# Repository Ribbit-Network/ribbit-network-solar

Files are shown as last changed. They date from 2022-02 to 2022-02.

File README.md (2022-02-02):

## Introduction

In the future, it would be cool for the Frog Sensor to be solar-powered. This folder documents the progress towards making that a reality.

Due to supply-chain uncertainty and the potential for future changes to the Frog Sensor's architecture, initial development towards a solar-powered Frog is focused on developing a self-contained solar battery charging system designed to supply power to a either a Frog Sensor V1 (Raspberry Pi), a Frog Sensor V2 (Beaglebone Black), or any future version with a different processor.

## Development

Check out the following pages for more details on development progress:
- [Proof of Concept]()

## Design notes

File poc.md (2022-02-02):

# Proof of Concept

This document hopes to provide a record of early prototyping progress. As mentioned in the [readme](README.md), the initial goal is to develop a solar-charged battery system that can provide enough power to reliably operate the Frog Sensor.

## Electronics

The following assumptions were applied to the initial electronics design in order to reduce complexity:
- The battery will be a 2-cell series NiMH
- The solar panel will provide a regulated 5V supply 

### Schematic

### Parts List

| Description | P/N (w link) | Cost | Qty |
|---|---|---|-----|
| PMOS | | | |
| | | | |
| | | | |
| | | | |

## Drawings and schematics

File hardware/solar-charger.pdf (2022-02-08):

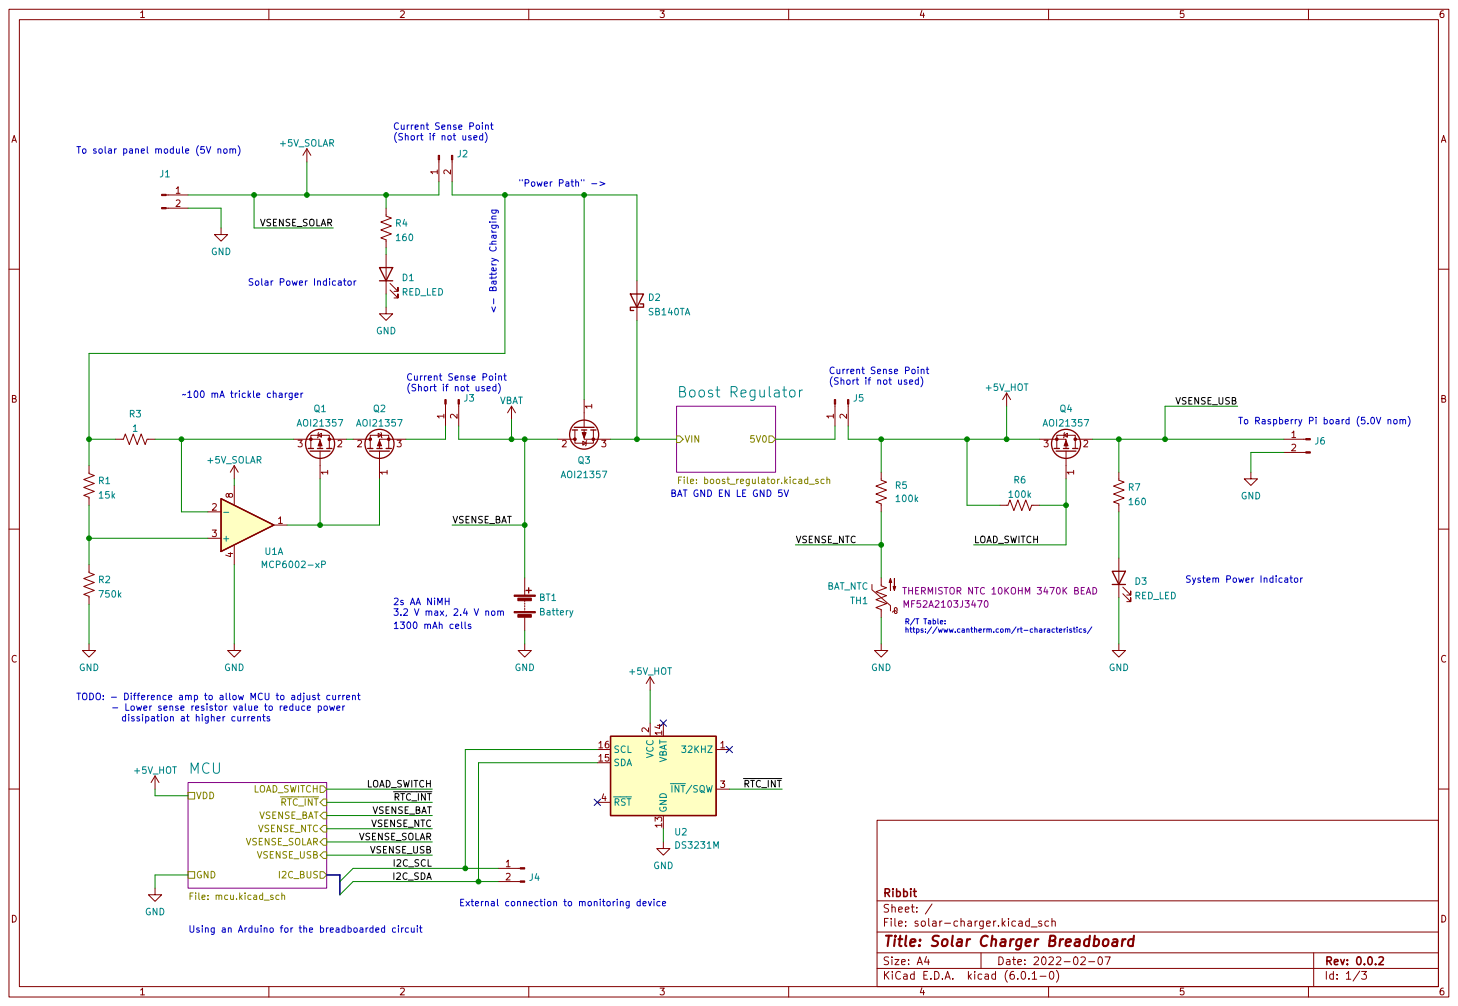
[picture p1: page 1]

To Raspberry Pi board (5.0V nom) 2s AA NiMH

TODO: - Difference amp to allow MCU to adjust current
- Lower sense resistor value to reduce power

VSENSE_SOLAR
File: solar-charger.kicad_sch Sheet: / Ribbit VSENSE_USB

External connection to monitoring device

Id: 1/3 Title: Solar Charger Breadboard

Using an Arduino for the breadboarded circuit

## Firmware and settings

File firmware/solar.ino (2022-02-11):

#include <avr/sleep.h>

#include <DS3231.h>
#include <Wire.h>

#define VSENSE_BAT   A0
#define VSENSE_NTC   A1
#define VSENSE_SOLAR A2
#define VSENSE_USB   A3

#define RTC_INTERRUPT 2
#define LOAD_SWITCH 10

#define CMD_READ_VOLTAGE    0xa1
#define CMD_SCHEDULE_SLEEP  0xa2

volatile int transaction_complete = true;
volatile int new_command = false;
volatile uint8_t command_response[2] = {0x0, 0x0};
volatile int rtc_alarm = false;

#define CMD_BUF_LEN 2
volatile uint8_t cmd_buffer[CMD_BUF_LEN];

void receive_command(int bytes_in) {
  transaction_complete = false;

  for (int i = 0; i < bytes_in; i++) {
    if (i < CMD_BUF_LEN) {
      cmd_buffer[i] = Wire.read();
    } else {
      // drop
      Wire.read();
    }
  }

  new_command = true;
}

void respond_command(void) {
  Wire.write(command_response[0]);
  Wire.write(command_response[1]);
  command_response[0] = 0;
  command_response[1] = 0;
  transaction_complete = true;
}

void switch_load_on(void) {
  rtc_alarm = true;
  digitalWrite(LOAD_SWITCH, LOW);
}

DS3231 rtc;
RTClib rtc_lib;

void setup() {
  pinMode(RTC_INTERRUPT, INPUT_PULLUP);
  pinMode(LOAD_SWITCH, OUTPUT);
  digitalWrite(LOAD_SWITCH, LOW);
  
  attachInterrupt(digitalPinToInterrupt(RTC_INTERRUPT), switch_load_on, FALLING);

  Serial.begin(115200);

  Wire.begin(0x8);
  Wire.onReceive(receive_command);
  Wire.onRequest(respond_command);
 
  sleep_enable();
  set_sleep_mode(SLEEP_MODE_PWR_DOWN);
}

void loop() {

  sleep_mode();
  // Code resumes here when woken by I2C address match interrupt
  Serial.println("Up!");
  if (rtc.checkIfAlarm(1)) {
    Serial.println("Alarm is ringing!");
    // switch load on
    digitalWrite(LOAD_SWITCH, LOW);
  }
  rtc.turnOffAlarm(1);
  rtc_alarm = false;

  if (new_command == true) {
    process_command(cmd_buffer);
    clear_buffer();
    new_command = false;
  }
  
  while(!transaction_complete);
  delay(10);
}

uint16_t read_pin(int analog_pin_num) {
  int analog_pin;
  
  switch (analog_pin_num) {
    case 0:
      analog_pin = VSENSE_BAT;
      break;
    case 1:
      analog_pin = VSENSE_NTC;
      break;
    case 2:
      analog_pin = VSENSE_SOLAR;
      break;
    case 3:
      analog_pin = VSENSE_USB;
      break;
    default:
      analog_pin = A0;
  }

  return analogRead(analog_pin);
}

int process_command(volatile uint8_t* cmd_buffer) {
  int rc = 0;
  Serial.print("cmd: "); Serial.println(cmd_buffer[0], HEX);
  switch(cmd_buffer[0]) {
      case CMD_READ_VOLTAGE:
      {
        // adc val is 10 bits, round down to 8 bits for command
        uint16_t pin_voltage = read_pin(cmd_buffer[1]);
        Serial.print("voltage: "); Serial.println(pin_voltage); 
        command_response[0] = (uint8_t) pin_voltage;
        command_response[1] = (uint8_t) (pin_voltage >> 8) & 0xFF;

        break;
      }
      case CMD_SCHEDULE_SLEEP:
      {
        // cmd_buffer[1] is number of seconds in the future to schedule (max 60 for now)
        DateTime time_now = rtc_lib.now();
        uint8_t new_seconds = (time_now.second() + cmd_buffer[1]) % 60;
        uint8_t new_minutes = time_now.minute() + (time_now.second() + cmd_buffer[1]) / 60;
        Serial.print(new_minutes); Serial.print("|"); Serial.println(new_seconds);
        rtc.setA1Time(time_now.day(), time_now.hour(), new_minutes, new_seconds,
                      0b00000, 0, 0, 0);
        rtc.turnOnAlarm(1);
        // switch the load off
        digitalWrite(LOAD_SWITCH, HIGH);
        transaction_complete = true;
        break;
      }
      default:
        Serial.println("Unknown!");
        transaction_complete = true;
  }
  
  return rc;
}

void clear_buffer(void) {
  for (int i = 0; i < CMD_BUF_LEN; i++) {
    cmd_buffer[i] = 0;
  }
}
    

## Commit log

2022-02-02 WIP solar charger schematics
    [boost_regulator.kicad_sch, mcu.kicad_sch, solar-charger.kicad_pcb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]
2022-02-02 Design updates
    [boost_regulator.kicad_sch, ina219.kicad_sch, mcu.kicad_sch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]
2022-02-02 Restructure project to seperate CAD and firmware
    [boost_regulator.kicad_sch, ina219.kicad_sch, mcu.kicad_sch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]
2022-02-02 Add TODO
    [solar-charger.kicad_sch]
2022-02-02 Add NTC circuit
    [mcu.kicad_sch, solar-charger.kicad_sch]
2022-02-02 Add op amp for current control circuit
    [solar-charger.kicad_sch]
2022-02-02 Add 200 mA (0.1C) trickle charger, neaten up schematic
    [mcu.kicad_sch, solar-charger.kicad_sch]
2022-02-02 Add external I2C connection, LED resistors, op-amp power connections
    [mcu.kicad_sch, solar-charger.kicad_sch]
2022-02-02 export schematic
2022-02-02 add RTC, change charge current based on revised capacity of 1300mAh
    [solar-charger.kicad_sch]
2022-02-02 firmware: I2C protocol up, needs schedule power off functionality
2022-02-02 Reorganize project structure after switching repos
    [boost_regulator.kicad_sch, ina219.kicad_sch, mcu.kicad_sch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]
2022-02-04 hardware: Add gitignore for Kicad files
2022-02-04 hardware: Replace power path MOSFET with Schottky
    MOSFET has a reverse leakage current over the body diode, which brings
    voltage back onto the `5V_SOLAR` net, turning off Q2. We want `5V_SOLAR`
    to be near 0V to ensure that Q2 turns on well. Therefore, we need to use
    a diode here to block the reverse leakage current. A Schottky has a low
    voltage drop so seems like an appropriate choice. Further improvement
    may be made with a ideal diode solution.
    [solar-charger.kicad_sch]
2022-02-08 hardware: Add Q2 to prevent discharging battery from 5V_SOLAR net, misc cleanup
    The body diode of Q1 allowed current to be conducted back into the solar
    panel. This is something that can happen during the night in a typical
    solar panel circuit. I don't know what our solar panel module looks like
    internally so add this just in case.
    [boost_regulator.kicad_sch, mcu.kicad_sch, solar-charger.kicad_sch]
2022-02-11 hardware: Replace current sense with a schottky, scrap blocking FET Q2
    We discovered that we require a diode anyways, so to be a bit more
    efficient, replace the fairly large current sense resistor with a
    schottky. This required that we updated the voltage divider values to
    reflect the new required voltage drop.
    Future work here is to consider the worst case highest temperature we
    want to support, and then add in a digipot to allow the micro to adjust
    the voltage (and therefore the current) up from that point.
    [solar-charger.kicad_sch]
2022-02-11 firmware: Increase bytes in command response to 2
    The ADC data requires 2 byte to represent the data fully.
